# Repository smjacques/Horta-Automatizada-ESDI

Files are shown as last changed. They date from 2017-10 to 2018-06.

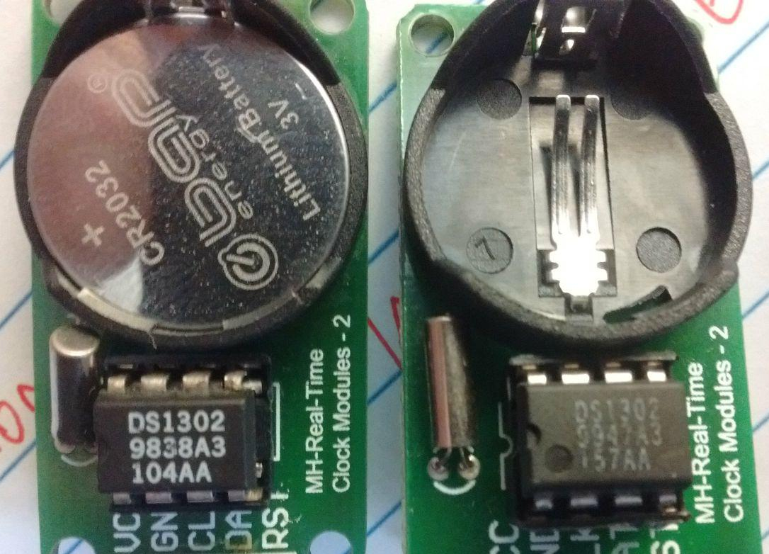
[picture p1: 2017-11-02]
issue img/RTC_modules_detail.jpg

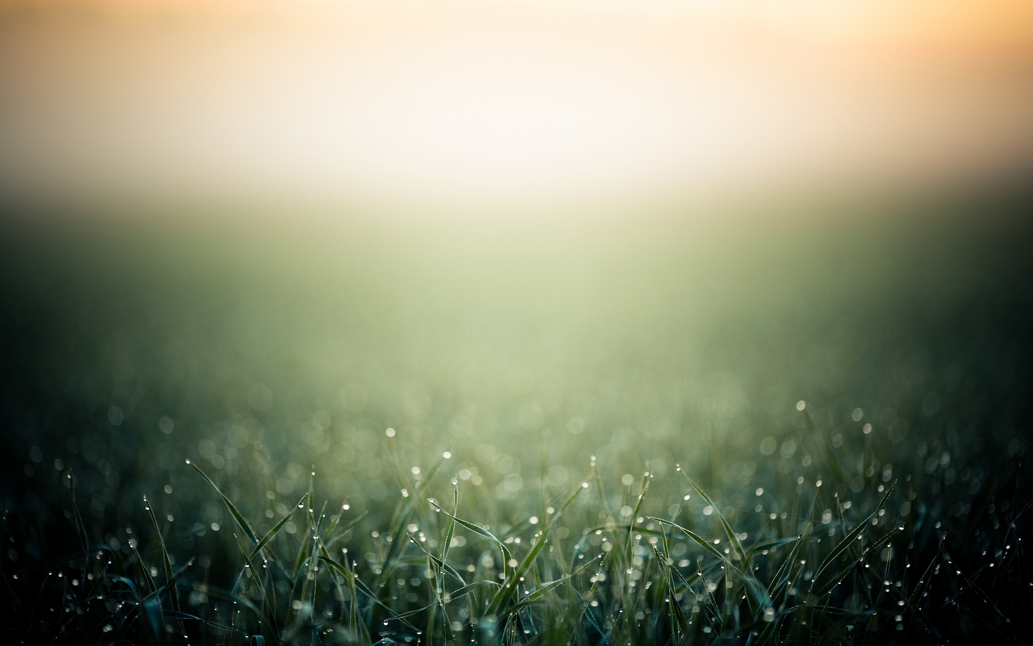
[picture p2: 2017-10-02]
imagens/morning-grass-hd-wallpaper.jpg

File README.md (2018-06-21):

# Automated Garden - ESDI
"Low Cost Watering System Using Microcontroller" - Course Presented at the School of Industrial Desing ( ESDI - Rio de Janeiro - Brazil)


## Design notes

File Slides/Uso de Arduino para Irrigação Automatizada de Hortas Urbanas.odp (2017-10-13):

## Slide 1

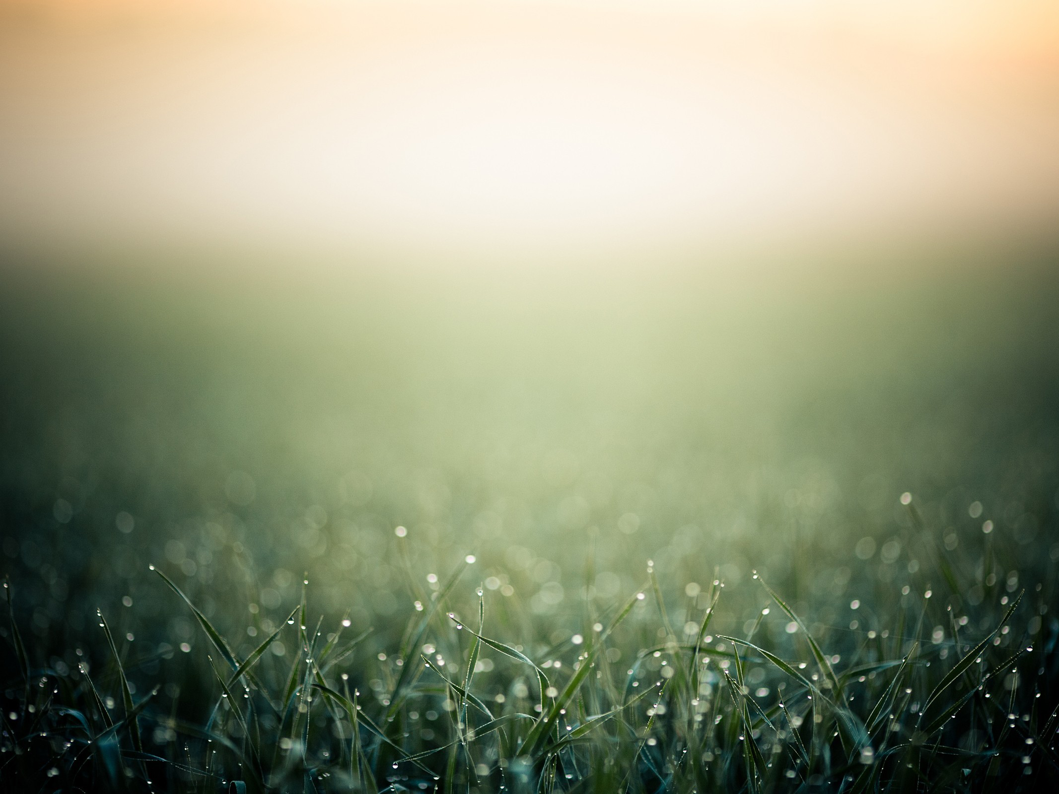
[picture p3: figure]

Uso de Arduino para Irrigação Automatizada de Baixo Custo

## Irrigação Automatizada de Hortas Urbanas

  Aplicações
- Agricultura urbana
- Hortas residenciais
- Sistemas Agroflorestais

“Uso de Arduino para Irrigação Automatizada de Baixo Custo”, de Saulo Jacques pode ser copiada, distribuída e utilizada em obras derivadas, desde que utilizada licença idêntica e atribuído créditos devidos ao autor. Creative Commons - Atribuição-CompartilhaIgual 4.0 Internacional.

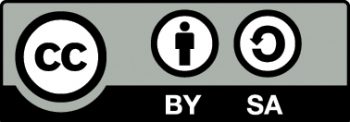
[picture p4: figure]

## Irrigação Automatizada de Hortas Urbanas

  Potencial
- Integração com projetos de captação de água da chuva
- Uso eficiente de água
- Irrigação de pequenas e médias produções
- Adequação a necessidades e condições climáticas específicas de diferentes regiões
- Adequação a demanda hídricas de diferentes grupos vegetais

## Irrigação Automatizada de Hortas Urbanas

A adoção dessa técnica não visa a substituição do contato das pessoas com a terra por um sistema 100% automatizado, mas um equilíbrio entre o resgate da agricultura em grandes centros urbanos, integrado ao uso eficiente de recursos naturais.

## Irrigação Automatizada de Hortas Urbanas

Componentes

Arduino

Protoboard

Cabo conexão com laptop

Relé (relay)

Válvula solenóide

Mangueira

Ferramentas

Fios

Fita isolante

Chave de fenda

Estilete

Algodão (ou terra)

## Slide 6

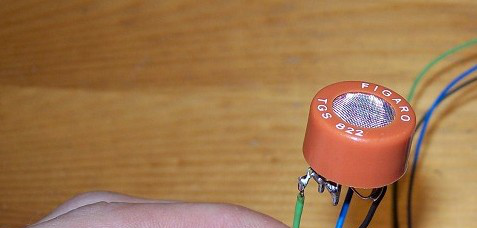
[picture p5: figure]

Componentes

## Irrigação Automatizada de Hortas Urbanas

O Relé (ou Relay)

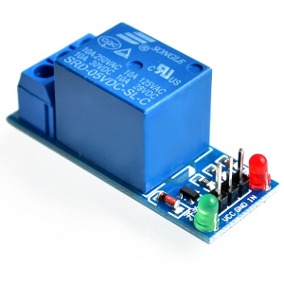
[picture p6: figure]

Circuito elétrico usado para fechar/abrir circuito sem necessidade de intervenção

## Irrigação Automatizada de Hortas Urbanas

Válvula Solenoide

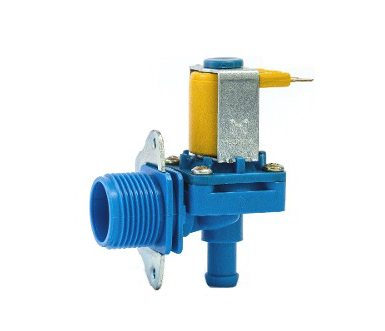
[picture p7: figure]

Válvula que se abre e se fecha respondendo ao campo magnético gerado por um solenoide ou um eletroímã

## Irrigação Automatizada de Hortas Urbanas

Módulo RTC

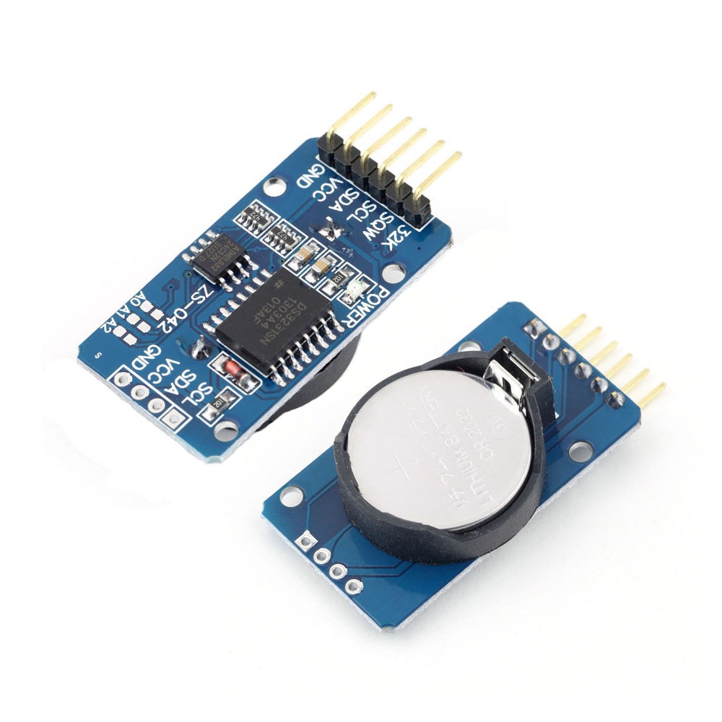
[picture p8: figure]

Relógio de tempo real

Bateria que garante autonomia para fornecer informações de segundo, minutos, dia, data, mês e ano.

## Irrigação Automatizada de Hortas Urbanas

Medindo a Umidade Usando Arduino

O sensor utilizado funciona como um resistor que varia em relação à quantidade de água no solo: quanto mais água, maior condutividades e menor resistência.

Resultados obtidos com os sensores: Resistência

Alta concentração de água → Menores valores de output

Baixa concentração de água → Maiores valores de output

## Irrigação Automatizada de Hortas Urbanas

Lendo a Umidade do Solo com Arduino

Arquivo: esquema1_automatizada.ino

## Irrigação Automatizada de Hortas Urbanas

int val_umid = 0; // sensor de umidade

void setup() {

Serial.begin(9600);

}

void loop() {

int umidade = analogRead(val_umid);

//convertendo o valor bruto em % de umidade

umidade = constrain(umidade,400,1023);

umidade = map(umidade,400,1023,100,0);

Serial.println("Umidade (valor bruto)");

Serial.println(val_umid);

Serial.println("Umidade (%)");

Serial.println(umidade);

}

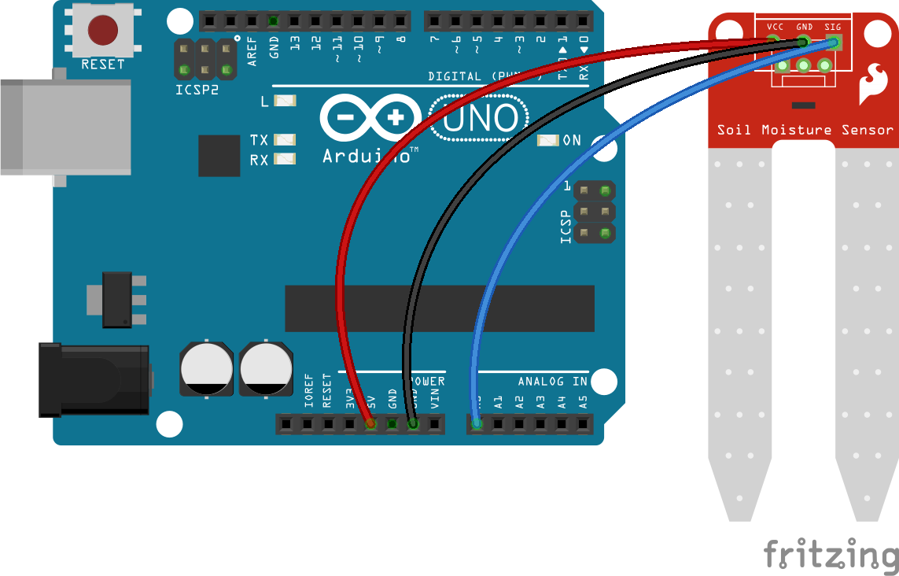
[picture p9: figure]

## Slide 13

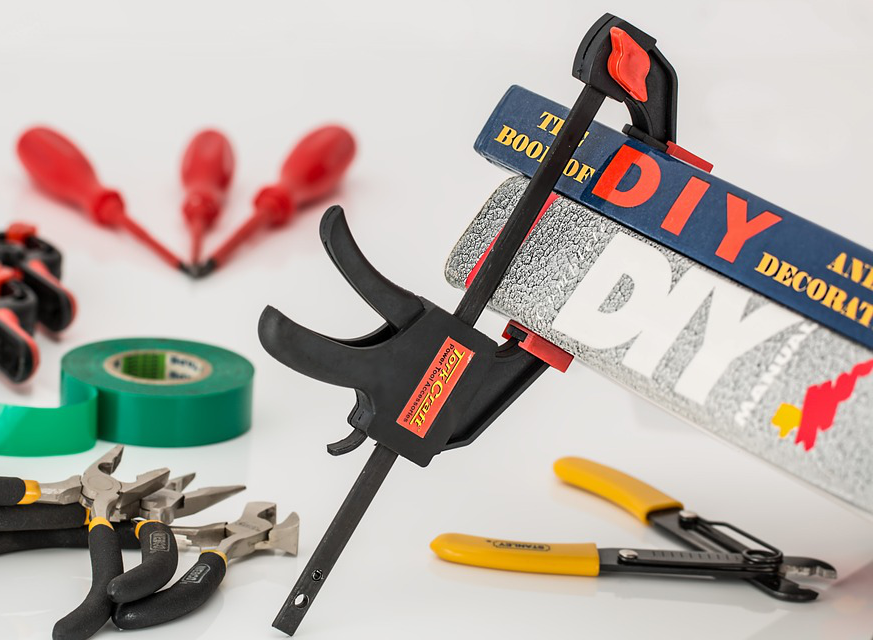
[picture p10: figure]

Sensor de Umidade DIY!

## Irrigação Automatizada de Hortas Urbanas

Materiais

- Fios de tamanho adequado
- Pregos ou arames de material condutivo, mas difícil de oxidar (geralmente galvanizados)
- Material isolante para suporte (Isopor/ EVA)
- Material para soldagem
- Cola de silicone

## Irrigação Automatizada de Hortas Urbanas

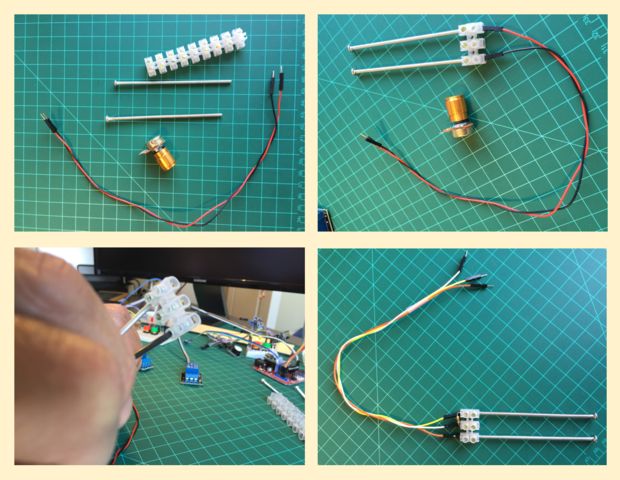
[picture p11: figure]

## Irrigação Automatizada de Hortas Urbanas

Detectando Baixa Umidade do Solo

Arquivo: esquema2_led.ino

## Irrigação Automatizada de Hortas Urbanas

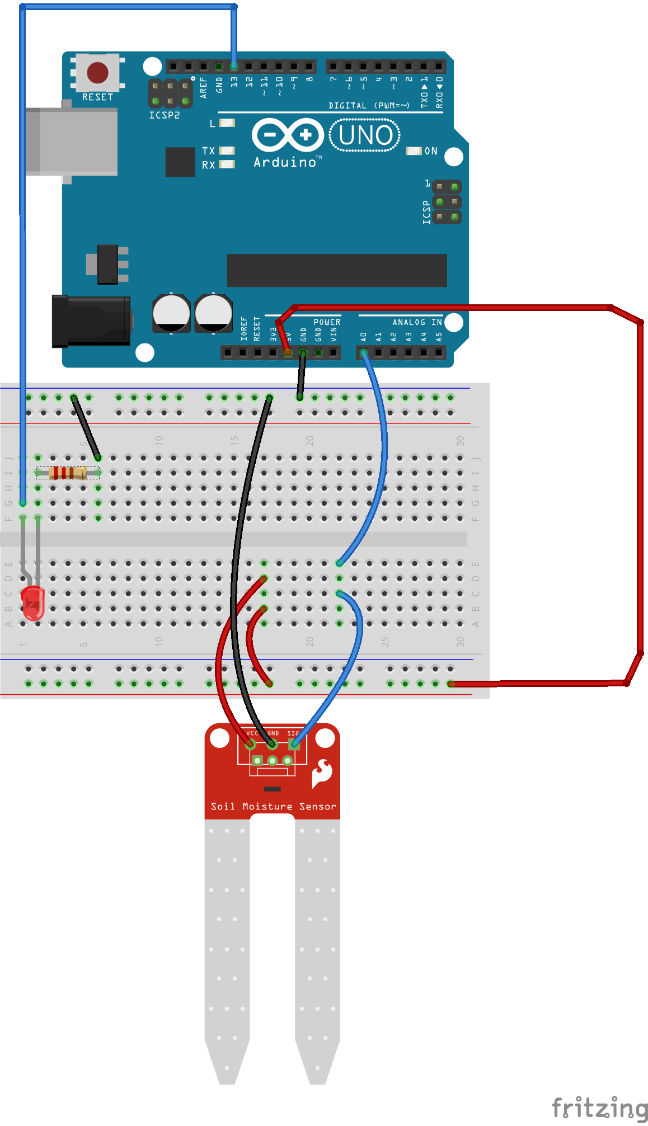
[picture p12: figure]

int val_umid = 0; // sensor de umidade

int umidade=0;

void setup() {

Serial.begin(9600);

}

void led(int state) {

digitalWrite(8, state);

}

## Irrigação Automatizada de Hortas Urbanas

void loop() {

umidade = analogRead(val_umid);

//intervalo dos resultados brutos entre seca e úmido

umidade = constrain(umidade,400,1023);

//convertendo os resultados em porcentagem de umidade (0 e 100%)

umidade = map(umidade,400,1023,100,0);

Serial.println(umidade);

if (umidade< 40) {

led(HIGH); }

else {

led(LOW); }

delay(2000);

}

## Irrigação Automatizada de Hortas Urbanas

Detectando Baixa Umidade do Solo &

Automatizando o Sistema

Arquivo: esquema3_automatizada.ino

## Irrigação Automatizada de Hortas Urbanas

int val_umid = 0; // sensor de umidade

int solenoide = 8; // porta ativa a solenoide

void setup() {

Serial.begin(9600);

}

void rega(int state) {

digitalWrite(solenoide, state);

}

## Irrigação Automatizada de Hortas Urbanas

void loop() {

int umidade = analogRead(val_umid);

umidade = constrain(umidade,400,1023);

umidade = map(umidade,400,1023,100,0);

Serial.println(umidade);

if(umidade< 40) {

rega(HIGH);

} else {

rega(LOW);

}

delay(2000);

}

## Irrigação Automatizada de Hortas Urbanas

Usando Tempo Para Controlar a Rega

Arquivo: esquema4_tempo_de_rega.ino

## Irrigação Automatizada de Hortas Urbanas

int val_umid = 0; // sensor de umidade

int umidade=0;

int solenoide = 8; // ativar led quando seco

int TempoRega = 10000; //definir tempo de rega (10 secs operando)

void setup() {

Serial.begin(9600);

pinMode(solenoide, OUTPUT); //pin do solenoide

digitalWrite(solenoide, LOW); //certifica-se que a solenoide inicia deligada (LOW)

}

## Irrigação Automatizada de Hortas Urbanas

void loop() {

umidade = analogRead(val_umid);

umidade = constrain(umidade,400,1023); //intervalo entre seca e úmido

umidade = map(umidade,400,1023,100,0);

Serial.println(umidade);

if (umidade < 40) {

digitalWrite(solenoide, HIGH);

delay(TempoRega);

digitalWrite(solenoide, LOW);

}

}

## Irrigação Automatizada de Hortas Urbanas

Incluindo os Dados do RTC

Arquivo: esquema5_RTC.ino

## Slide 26

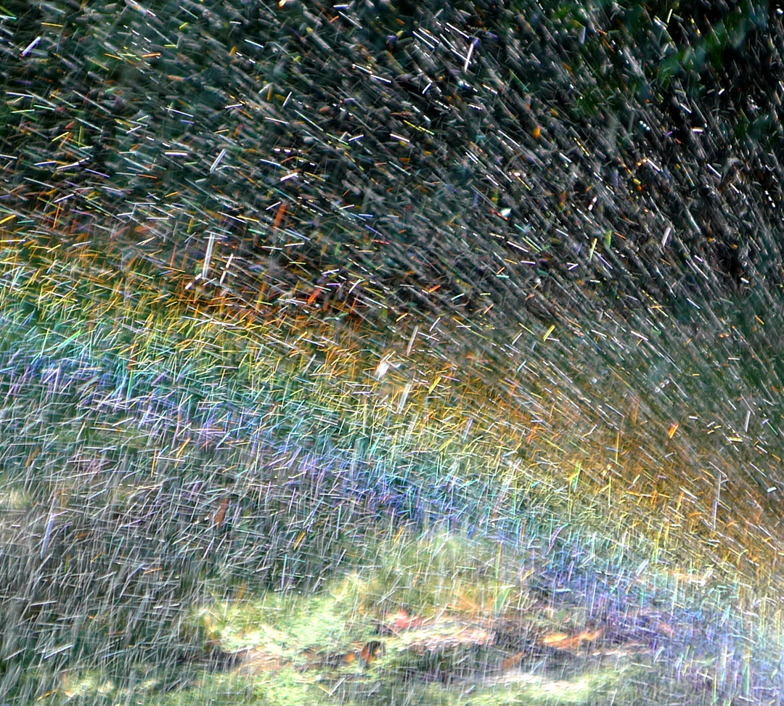
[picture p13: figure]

Criando Nosso Protótipo (v0.1_esdi)

Arquivo: esquema5_RTC.ino

## Irrigação Automatizada de Hortas Urbanas

// Carrega a biblioteca virtuabotixRTC

#include <virtuabotixRTC.h>

//Sensor de umidade

int val_umid = 0;

int umidade=0;

// Valvula solenoide

int solenoide = 8; // ativar led quando seco

// Determina os pinos ligados ao modulo

// myRTC(clock, data, rst)

virtuabotixRTC myRTC(10, 9, 8);

const int H1 = 17; // hora medida 1

const int M1 = 07; // minuto medida 1

const int H2 = 17; // hora medida 2

const int M2 = 11; // minuto medida 2

// Denfinindo umidade limite e tempo de rega

const int umidade_min = 40; // 80%

int TempoRega = 10000; //10 secs operando

## Irrigação Automatizada de Hortas Urbanas

void setup() {

Serial.begin(9600);

//certificar que a solenoide inicia deligada (LOW)

digitalWrite(solenoide, LOW);

//definir solenoide como saida

pinMode(solenoide, OUTPUT);

}

## Irrigação Automatizada de Hortas Urbanas

void loop()

{

// Ler as informacoes do CI

myRTC.updateTime();

imprime_tempo();

int hora = myRTC.hours;

int minutos = myRTC.minutes;

// verifica se chegou a hora de ler a umidade

if ((hora == H1 && minutos == M1) || (hora == H2 && minutos == M2) ) {

Serial.println("medindo...");

## Irrigação Automatizada de Hortas Urbanas

// ler umidade

umidade = analogRead(val_umid);

//intervalo entre seca e úmido

umidade = constrain(umidade,400,1023);

// convertendo em %

umidade = map(umidade,400,1023,100,0);

imprime_umidade();

// verificar se a umidade está abaixo do minimo

if (umidade < umidade_min ) {

Serial.println("abrindo válvula...");

digitalWrite(solenoide, HIGH);

delay(TempoRega);

Serial.println("fechando valvula...");

digitalWrite(solenoide, LOW);

} // fim do if da umidade

}

}

## Irrigação Automatizada de Hortas Urbanas

void imprime_umidade() {

Serial.print("Umidade : ");

Serial.print(umidade);

Serial.println("%");

}

## Irrigação Automatizada de Hortas Urbanas

void imprime_tempo() {

// Imprime as informacoes no serial monitor

Serial.print("Data : ");

Serial.print(myRTC.dayofmonth);

Serial.print("/");

Serial.print(myRTC.month);

Serial.print("/");

Serial.print(myRTC.year);

Serial.print(" ");

Serial.print("Hora : ");

## Irrigação Automatizada de Hortas Urbanas

// Adiciona um 0 caso o valor da hora seja <10

if (myRTC.hours < 10)

{

Serial.print("0");

}

Serial.print(myRTC.hours);

Serial.print(":");

// Adiciona um 0 caso o valor dos minutos seja <10

if (myRTC.minutes < 10)

{

Serial.print("0");

}

Serial.print(myRTC.minutes);

Serial.print(":");

// Adiciona um 0 caso o valor dos segundos seja <10

if (myRTC.seconds < 10)

{

Serial.print("0");

}

Serial.println(myRTC.seconds);

}

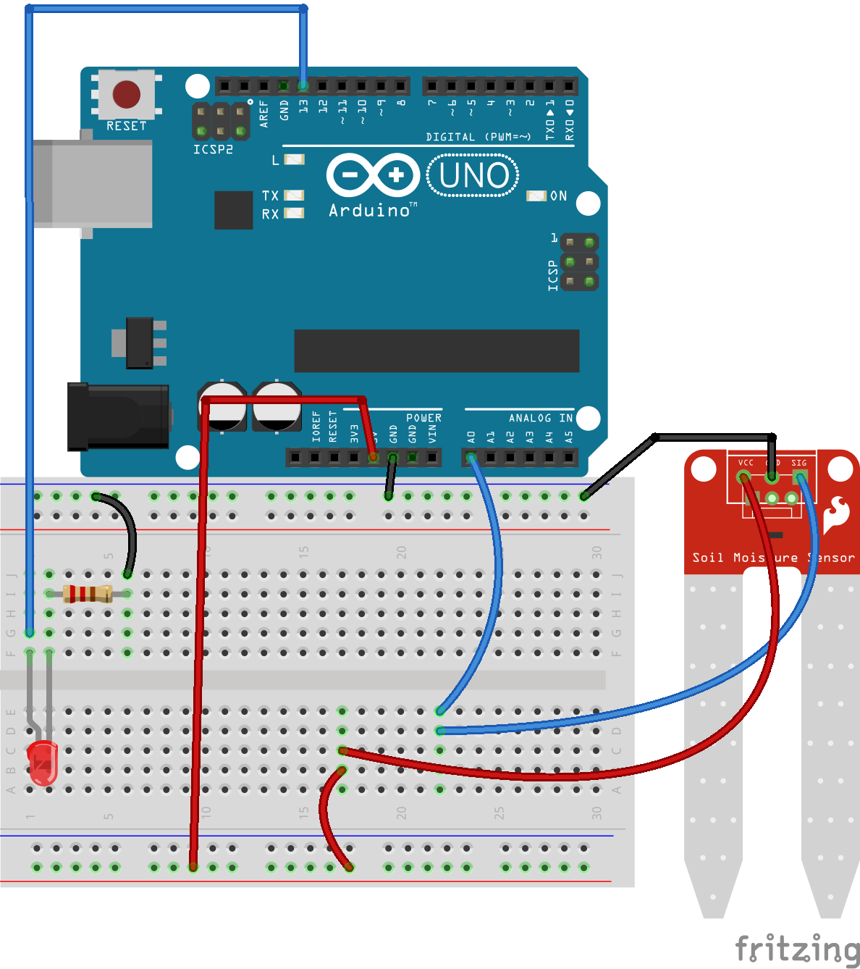
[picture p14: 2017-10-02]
imagens/oficina_led_verm_bb.png

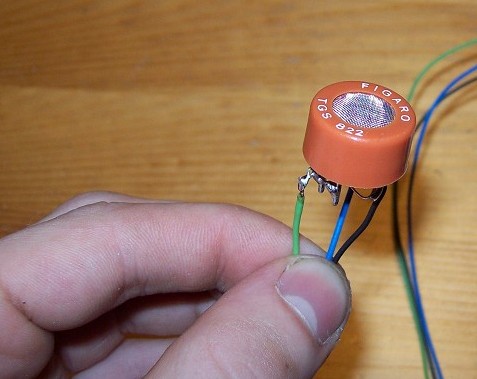
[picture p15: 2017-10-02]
imagens/Gassensor_tgs822.jpg

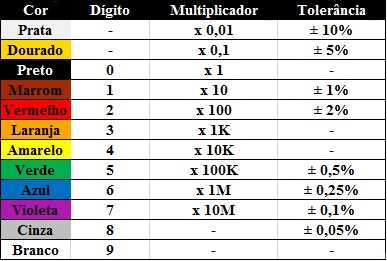
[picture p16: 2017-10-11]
imagens/Tabela_de_cores_de_um_resistor.jpg

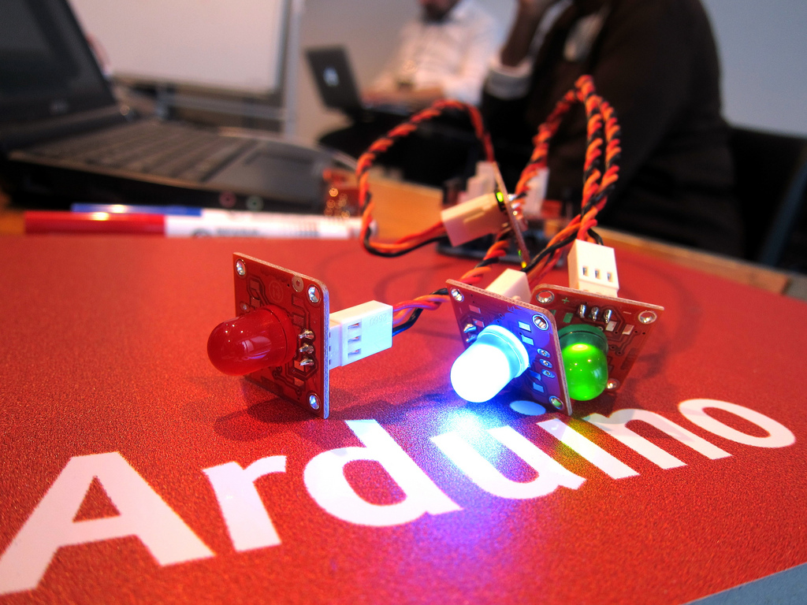
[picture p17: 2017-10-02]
imagens/5146390498_2d04c900f4_b.jpg

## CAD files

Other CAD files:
caixa do sistema/IrrigaBox.dxf

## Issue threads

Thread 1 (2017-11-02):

Problemas com a data no módulo RTC durante o curso

smjacques, 2017-11-02:
Problema com a data e a hora no RTC

Durante o curso, todas as tentativas que fizemos com os módulos RTC retornaram a estranha informação 0/0/2000 00:00:01 (ou 00:00:01, em alguns casos).
Hoje fiz os testes utilizando diferentes bibliotecas: DS1302.h e outras versões da biblioteca utilizada no código original (virtuabotixRTC.h).
Nenhuma delas com resultados diferentes do encontrado. o RTC é apenas o chip presente no módulo, e após alguns testes pensei em pressionálo junto à placa. Isso alterou os resultados. De 2000, o ano saltou para 2145 (talvez tenha descoberto algo interessante sobre viagem no tempo, mas um problema de cada vez).

RTC extra

Por sorte tinha um outro RTC que usei no protótipo a ser instalado na ESDI. Conectei e carreguei o código no arduino mais uma vez e... voilà! Tudo ok, como mostra a figura abaixo (uma com a data de um código antigo que utilizei e um com a data atualizada pro dia de hoje).

Uma possível causa: O RTC que funcionou é muito diferente do que não ajustava a data. Ambos são DS1302, mas alguns números abaixo (bem como a qualidade da tinta usada) são bem distintos entre eles.

Superemos! Já estava realmente cogitando utilizar o timer que já vem embutido no arduino (que é a base pra funçao delay, por exemplo).

Então ficamos combinados: o código tá ok. Se houver algum problema, já sabemos que estará nno chip RTC ou, mais tranquilo de se resolver, na conexão dos jumpers.

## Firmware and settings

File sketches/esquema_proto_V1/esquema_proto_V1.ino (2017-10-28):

// Carrega a biblioteca virtuabotixRTC
#include <virtuabotixRTC.h>
//Carrega a biblioteca LiquidCrystal
#include <LiquidCrystal.h>

//Define os pinos que serão utilizados para ligação ao display
LiquidCrystal lcd(12, 11, 5, 4, 3, 2);

//Sensor de umidade
int val_umid = 0;
int umidade=0;

// Valvula solenoide
int solenoide = 4; // ativar led quando seco

// Determina os pinos ligados ao modulo
// myRTC(clock, data, rst)
virtuabotixRTC myRTC(10, 9, 8);

const int H1 = 17; // hora medida 1
const int M1 = 07; // minuto medida 1

const int H2 = 17; // hora medida 2
const int M2 = 11; // minuto medida 2

// Denfinindo umidade limite e tempo de rega
const int umidade_min = 40; // 80%

int TempoRega = 10000; //10 secs operando

    
void setup() {
  Serial.begin(9600);
  //certifica-se que a solenoide inicia deligada (LOW)
  lcd.begin(16, 2); 
  digitalWrite(solenoide, LOW);
  //define como saida
  pinMode(solenoide, OUTPUT);
  
}

void loop()
{
  //Limpa a tela do LCD
  lcd.clear();  
  //Posiciona o cursor na coluna 3, linha 0;
  lcd.setCursor(3, 0);
  //Envia o texto entre aspas para o LCD
  lcd.print("ESDI - UERJ");
delay(500);
  lcd.setCursor(1, 1);
  lcd.print("Espacos Verdes ESDI");
  delay(1200);
  
  // Ler as informacoes do CI
  myRTC.updateTime();
  imprime_tempo();

  int hora = myRTC.hours;
  int minutos = myRTC.minutes;
  
  // verifica se chegou a hora de ler a umidade
  if ((hora == H1 && minutos == M1) || (hora == H2 && minutos == M2) ) {
    Serial.println("medindo...");
    // ler umidade
    umidade = analogRead(val_umid);    
    umidade = constrain(umidade,400,1023); //intervalo entre seca e úmido
    umidade = map(umidade,400,1023,100,0); // convertendo em %
    imprime_umidade();
    
    // verifica se a umidade está abaixo do minimo
    if (umidade < umidade_min ) {
      Serial.println("abrindo válvula...");
      digitalWrite(solenoide, HIGH);
      delay(TempoRega);
      Serial.println("fechando valvula...");
      digitalWrite(solenoide, LOW);
    } // fim do if da umidade
  }
}


void imprime_umidade() {
  Serial.print("Umidade : ");
  Serial.print(umidade);
  Serial.println("%");
}
void imprime_tempo() {
  // Imprime as informacoes no serial monitor
  Serial.print("Data : ");
  Serial.print(myRTC.dayofmonth);
  Serial.print("/");
  Serial.print(myRTC.month);
  Serial.print("/");
  Serial.print(myRTC.year);
  Serial.print("  ");
  Serial.print("Hora : ");
  // Adiciona um 0 caso o valor da hora seja <10
  if (myRTC.hours < 10)
  {
    Serial.print("0");
  }
  Serial.print(myRTC.hours);
  Serial.print(":");
  // Adiciona um 0 caso o valor dos minutos seja <10
  if (myRTC.minutes < 10)
  {
    Serial.print("0");
  }
  Serial.print(myRTC.minutes);
  Serial.print(":");
  // Adiciona um 0 caso o valor dos segundos seja <10
  if (myRTC.seconds < 10)
  {
    Serial.print("0");
  }
  Serial.println(myRTC.seconds);
  
  //LCD output
  
  //Limpar a tela do LCD
  lcd.clear();
  lcd.setCursor(0, 0);
  //Texto para o LCD
  lcd.print("lendo umidade"); 
  delay(300);
  lcd.setCursor(13, 0);
  lcd.print("."); 
  delay(300);
  lcd.setCursor(13, 0);
  lcd.print(".."); 
  delay(300);
  lcd.setCursor(13, 0);
  lcd.print("..."); 
  delay(300);
  lcd.setCursor(6, 1); //Posiciona o cursor na coluna 6, linha 1;
  lcd.print(umidade);
  lcd.setCursor(9, 1);
  lcd.print("%");
  delay(1500);
     
  if(umidade< umidade_min) {
  lcd.clear();//Limpa a tela do LCD
  lcd.setCursor(2, 0);//Posiciona o cursor na coluna 2, linha 0;
  lcd.print("umidade baixa");
  delay(500);
  lcd.setCursor(5, 1);
  lcd.print("REGAR");
  delay(300);
  lcd.setCursor(10, 1);
  lcd.print("!");
  } else   {
  lcd.clear();//Limpa a tela do LCD
  lcd.setCursor(2, 0);
  lcd.print("umidade OK");
  delay(500);
  lcd.setCursor(1, 1);
  delay(300);
  lcd.setCursor(15, 1);
lcd.print("!");
  }
}

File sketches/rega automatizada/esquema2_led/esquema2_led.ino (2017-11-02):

/*testa o % de umidade e acende o LED quando abaixo de 40%
*/

int val_umid = 0; // sensor de umidade
int umidade=0;
    
void setup() {
  Serial.begin(9600);
}

  void led(int state) {
  digitalWrite(13, state);
  }

void loop() {
  umidade = analogRead(val_umid);    
  umidade = constrain(umidade,400,1023); //intervalo dos resultados brutos entre seca e úmido
  umidade = map(umidade,400,1023,0,100); //convertendo os resultados em porcentagem de umidade (0 e 100%)

  Serial.println(umidade);
     
  if(umidade< 40) {
  led(HIGH);
  } else   {
  led(LOW);
  }

delay(2000);

    }

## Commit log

2017-10-14 pictures, sketches and slides updated
    [oficina_automatizada.fzz, prototipo_v0.1_esdi.fzz, sens_umid_DIY.fzz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]
2017-10-28 folder updated
    [IrrigaBox.dxf, prototipo_lcd_esdi.fzz, prototipo_v0.1_esdi.fzz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]
2017-11-02 presentation updated and issue img added
    [esquema2_led.ino, esquema3_automatizada.ino, esquema4_tempo_de_rega.ino]

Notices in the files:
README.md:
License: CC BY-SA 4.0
